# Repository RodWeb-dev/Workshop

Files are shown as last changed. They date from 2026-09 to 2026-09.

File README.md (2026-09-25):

# Workshop — Serre connectée

Un Arduino relève la température, l'humidité et la luminosité, et pilote le ventilateur, le chauffage et l'éclairage.
Il envoie ses mesures par port série à un Raspberry Pi 3, qui les enregistre dans une base SQLite et les affiche sur un tableau de bord web.

```text
Arduino ──(USB / série)──> collect.py ──> serre.db (SQLite) ──> data.php ──> index.php + script.js
```

## Arborescence

```text
WorkShop/
├── arduino/
│   └── codeOK_final.ino
├── impression3d/
│   ├── boitier yanis.stl
│   ├── couvercle yanis.stl
│   ├── helice yanis.stl
│   └── porte yanis.stl
├── raspberry/
│   ├── index.php
│   ├── data.php
│   ├── script.js
│   ├── style.css
│   ├── img/bg.jpg
│   ├── js/chart.umd.min.js
│   ├── db/
│   │   ├── schema.sql
│   │   └── serre.db
│   └── scripts/
│       └── collect.py
├── Dockerfile
└── docker-compose.yml
```

## Arduino

| Fichier | Rôle |
| --- | --- |
| `arduino/codeOK_final.ino` | Lit les capteurs (DHT22 pour la température et l'humidité, BH1750 pour la luminosité), active les équipements selon des seuils et envoie une ligne par mesure sur le port série à 9600 bauds. |

Chaque ligne contient les mesures et l'état des équipements, séparés par `|` :

```text
temp=22.5;hygro=60.0;lux=120.0|Ventilateur=OFF;Chauffage=OFF;Eclairage=ON
```

## Raspberry Pi

### Collecte

| Fichier | Rôle |
| --- | --- |
| `raspberry/scripts/collect.py` | Ouvre le port série (`/dev/ttyACM0`), attend 2 s que l'Arduino redémarre, ignore la première ligne puis lit les trames en continu. Enregistre les mesures dans `readings` et ouvre ou ferme un événement dans `events` à chaque changement d'état d'un équipement. |

### Base de données

| Fichier | Rôle |
| --- | --- |
| `raspberry/db/schema.sql` | Crée les tables et insère les trois équipements. |
| `raspberry/db/serre.db` | Base SQLite (ignorée par git). |

Tables :

- `readings` : une ligne par mesure (`temp`, `hygro`, `lux`, `recorded_at`).
- `equipements` : Ventilateur, Chauffage, Eclairage.
- `events` : périodes de fonctionnement d'un équipement (`started_at`, et `ended_at` qui reste vide tant que l'équipement est allumé).

Créer la base :

```bash
sqlite3 raspberry/db/serre.db < raspberry/db/schema.sql
```

### Tableau de bord web

| Fichier | Rôle |
| --- | --- |
| `raspberry/index.php` | Page principale : onglets température / humidité / luminosité, graphique et un voyant par équipement (généré depuis la table `equipements`). |
| `raspberry/data.php` | API JSON appelée par la page : dernière mesure, équipements actifs, 50 dernières mesures et statistiques par équipement (nombre de cycles, durée cumulée). |
| `raspberry/script.js` | Appelle `data.php` toutes les secondes, met à jour les valeurs, les voyants (classe `on`) et le graphique. |
| `raspberry/style.css` | Styles de la page. Un voyant est rouge par défaut et vert avec la classe `on`. |
| `raspberry/js/chart.umd.min.js` | Bibliothèque Chart.js, embarquée localement pour fonctionner sans internet. |
| `raspberry/img/bg.jpg` | Image de fond. |

## Impression 3D

| Dossier | Rôle |
| --- | --- |
| `impression3d/` | Modèles STL de la serre : boîtier, couvercle, hélice du ventilateur et porte. |

## Développement (Docker)

| Fichier | Rôle |
| --- | --- |
| `Dockerfile` | Image PHP 8.2 + Apache qui sert le dossier `raspberry/`. |
| `docker-compose.yml` | Lance le conteneur derrière Traefik, accessible sur `http://raspberry.test`. Le dossier `raspberry/` est monté en volume pour voir les modifications en direct. |

```bash
docker compose up -d --build
```

## Déploiement sur le Raspberry Pi

Le projet est développé dans le conteneur, puis copié sur le Raspberry Pi 3 par SSH.
Sur le Pi, il faut un serveur web avec PHP et l'extension SQLite3, ainsi que Python 3 avec `pyserial` pour `collect.py` :

```bash
python3 raspberry/scripts/collect.py
```

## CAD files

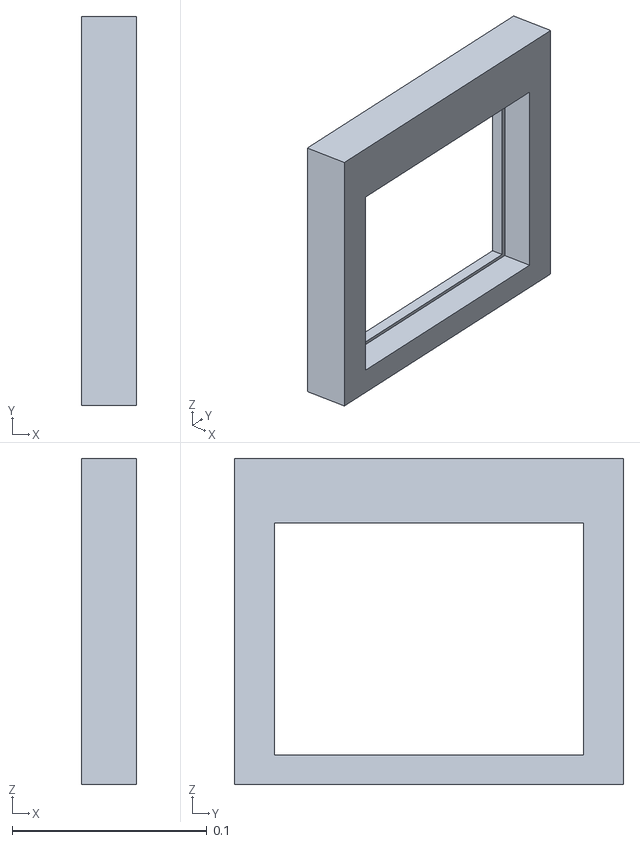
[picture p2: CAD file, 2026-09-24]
impression3d/porte yanis.stl
0.0281 x 0.2 x 0.168

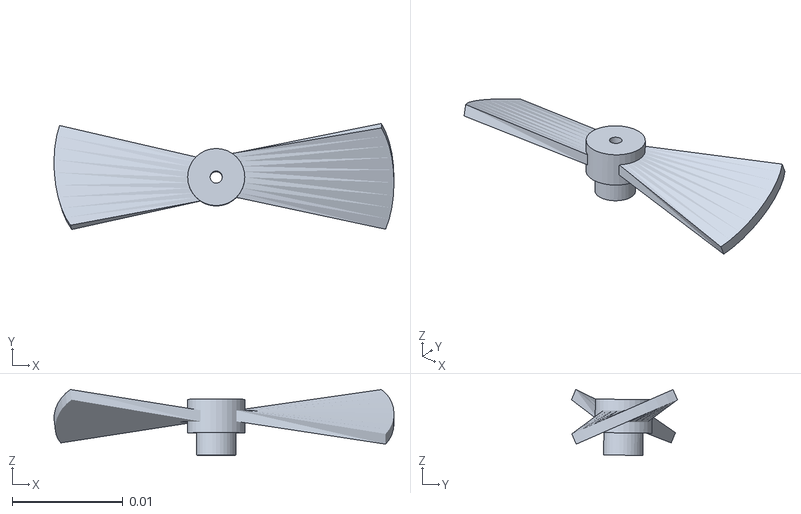
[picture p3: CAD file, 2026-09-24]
impression3d/helice yanis.stl
0.0308 x 0.0096 x 0.00597

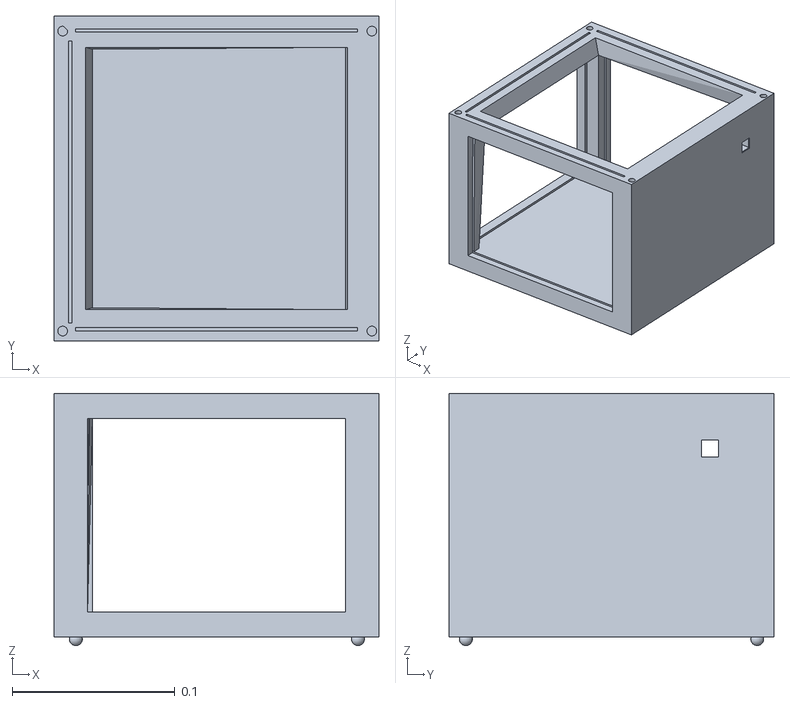
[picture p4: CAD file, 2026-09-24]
impression3d/boitier yanis.stl
0.2 x 0.2 x 0.155

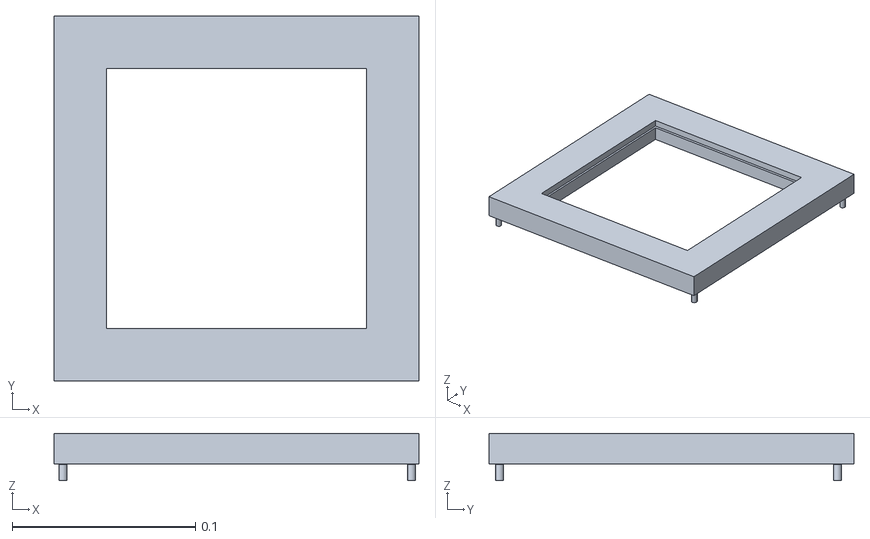
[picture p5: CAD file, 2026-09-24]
impression3d/couvercle yanis.stl
0.199 x 0.199 x 0.0258

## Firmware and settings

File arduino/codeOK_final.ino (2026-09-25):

#include <Wire.h>
#include <BH1750.h>
#include <DHT.h>

// --- Pins ---
const int LED1 = 4;
const int LED2 = 6;

const int FAN_ENA = 5;       // ENA L298N -> vitesse ventilateur
const int FAN_IN1 = 7;       // IN1 L298N
const int FAN_IN2 = 8;       // IN2 L298N

const int HEATER_PIN = 9;    // chauffage
const int DHTPIN = 2;

#define DHTTYPE DHT22        // mets DHT11 si besoin

// --- Seuils ---
const float SEUIL_LUM = 20;
const float T_CHAUFFE = 10 ;
const float T_STOP_CHAUFFE = 20;

const float T_VENTILO_MIN = 23;
const float T_VENTILO_MAX = 30;

BH1750 lightMeter;
DHT dht(DHTPIN, DHTTYPE);

bool chauffageOn = false;

void setup() {

  Serial.begin(9600);

  pinMode(LED1, OUTPUT);
  pinMode(LED2, OUTPUT);

  pinMode(FAN_ENA, OUTPUT);
  pinMode(FAN_IN1, OUTPUT);
  pinMode(FAN_IN2, OUTPUT);

  pinMode(HEATER_PIN, OUTPUT);

  digitalWrite(LED1, LOW);
  digitalWrite(LED2, LOW);

  digitalWrite(FAN_IN1, LOW);
  digitalWrite(FAN_IN2, LOW);

  analogWrite(FAN_ENA, 0);

  

  Wire.begin();
  dht.begin();

  if (lightMeter.begin(BH1750::CONTINUOUS_HIGH_RES_MODE)) {
    Serial.println("BH1750 OK");
  } else {
    Serial.println("BH1750 introuvable");
  }
}

void loop() {

  // ========== LUMIERE -> LED ==========

  float lux = lightMeter.readLightLevel();

  // Etat Eclairage
  bool eclairageOn;

  if (lux < SEUIL_LUM) {

    digitalWrite(LED1, HIGH);
    digitalWrite(LED2, HIGH);

    eclairageOn = true;

  } else {

    digitalWrite(LED1, LOW);
    digitalWrite(LED2, LOW);

    eclairageOn = false;
  }


  // ========== TEMPERATURE + HUMIDITE ==========

  float temp = dht.readTemperature();
  float hygro = dht.readHumidity();

  if (!isnan(temp) && !isnan(hygro)) {

    // ===== CHAUFFAGE =====

    if (temp < T_CHAUFFE) {
      chauffageOn = true;
      digitalWrite(HEATER_PIN,LOW);
  }

    if (temp >= T_STOP_CHAUFFE) {
      chauffageOn = false;
      digitalWrite(HEATER_PIN,HIGH);
    }


    // ===== VENTILATEUR =====

    int vitesseVentilo = 0;

    // Moins de 23°C -> 0%
    if (temp < 23) {

      vitesseVentilo = 0;

    }

    // 23°C à moins de 25°C -> environ 20%
    else if (temp >= 23 && temp < 25) {

      vitesseVentilo = 20;

    }

    // 25°C à moins de 27°C -> environ 31%
    else if (temp >= 25 && temp < 27) {

      vitesseVentilo = 30;

    }

    // 27°C à moins de 29°C -> environ 47%
    else if (temp >= 27 && temp < 29) {

      vitesseVentilo = 40;

    }

    // 29°C ou plus -> maximum 60%
    else {

      vitesseVentilo = 50;

    }


    // ===== SECURITE =====

    // Pas de chauffage quand le ventilateur fonctionne
    //if (vitesseVentilo > 0) {
    //  chauffageOn = false;
    //}


    // ===== COMMANDE VENTILATEUR =====

    if (vitesseVentilo > 0) {

      digitalWrite(FAN_IN1, HIGH);
      digitalWrite(FAN_IN2, LOW);

      analogWrite(FAN_ENA, vitesseVentilo);

    } else {

      digitalWrite(FAN_IN1, LOW);
      digitalWrite(FAN_IN2, LOW);

      analogWrite(FAN_ENA, 0);
    }


    // ===== CHAUFFAGE =====

   digitalWrite(
    HEATER_PIN,
      chauffageOn ? LOW : HIGH
    );


    // ==================================================
    // AFFICHAGE ORGANISE POUR LA BASE DE DONNEES
    // ==================================================

    // ----- GROUPE GAUCHE : readings -----

    Serial.print("temp = ");
    Serial.print(temp, 1);

    Serial.print(" ; ");

    Serial.print("hygro = ");
    Serial.print(hygro, 1);

    Serial.print(" ; ");

    Serial.print("lux = ");
    Serial.print(lux, 1);


    // ----- SEPARATION -----

    Serial.print(" | ");


    // ----- GROUPE DROITE : equipments -----

    Serial.print("Ventilateur = ");

    if (vitesseVentilo > 0) {
      Serial.print("ON");
    } else {
      Serial.print("OFF");
    }

    Serial.print(" ; ");

    Serial.print("Chauffage = ");
    Serial.print(chauffageOn ? "ON" : "OFF");

    Serial.print(" ; ");

    Serial.print("Eclairage = ");
    Serial.println(eclairageOn ? "ON" : "OFF");
  }


  // ========== ERREUR DHT ==========

  else {

    Serial.print("temp = ERROR ; ");

    Serial.print("hygro = ERROR ; ");

    Serial.print("lux = ");
    Serial.print(lux, 1);

    Serial.print(" | ");

    Serial.print("Ventilateur = ERROR");
    Serial.print(" ; ");

    Serial.print("Chauffage = ERROR");
    Serial.print(" ; ");

    Serial.println("Eclairage = ERROR");
  }

  delay(1000);
}

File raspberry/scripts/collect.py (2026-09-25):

# --- collect.py ---

import pathlib
import sqlite3
import time

import serial

path = pathlib.Path(__file__).parent.parent.resolve()

timeout = 3  # Délai d'attente pour la lecture du port série
rate = 9600  # Vitesse de communication du port série
port = "/dev/ttyACM0"  # Port série à utiliser

db = sqlite3.connect(path / "db/serre.db")
db.execute("PRAGMA foreign_keys = ON")

print("db connected")

equipements = {}
db_equipements = db.execute("SELECT id, name FROM equipements").fetchall()
for equipement_id, name in db_equipements:
    equipements[name] = {"ID": equipement_id, "Etat": False, "Event_id": None}


# Insérer les données dans la table readings
def insert_real_data(data):
    cursor = db.cursor()
    cursor.execute(
        "INSERT INTO readings (temp, hygro, lux) VALUES (?, ?, ?)",
        (data["temp"], data["hygro"], data["lux"]),
    )
    db.commit()


# Démarrer un événement dans la table events
def start_event(
    equipement_id,
):
    cursor = db.cursor()
    cursor.execute("INSERT INTO events (equipement_id) VALUES (?)", (equipement_id,))
    db.commit()
    return cursor.lastrowid


# Terminer un événement dans la table events
def end_event(
    event_id,
):
    cursor = db.cursor()
    cursor.execute(
        "UPDATE events SET ended_at = CURRENT_TIMESTAMP WHERE id = ?",
        (event_id,),
    )
    db.commit()


# parser les les données réelles reçues depuis le port série
def parse_real(text):
    real = text.split("|")[0]
    data = {}
    real = real.split(";")
    for paire in real:
        cle, valeur = paire.split("=")
        cle = cle.strip()
        valeur = valeur.strip()
        data[cle] = float(valeur)
    return data


# détecter les changements d'état des équipements et déclencher un événement si nécessaire
def parse_binary(text):
    binary = text.split("|")[1]
    binary = binary.split(";")
    for paire in binary:
        cle, valeur = paire.split("=")
        cle = cle.strip()
        valeur = valeur.strip()
        if valeur == "ON" and not equipements[cle]["Etat"]:
            equipements[cle]["Etat"] = True
            equipements[cle]["Event_id"] = start_event(equipements[cle]["ID"])
        elif valeur == "OFF" and equipements[cle]["Etat"]:
            equipements[cle]["Etat"] = False
            end_event(equipements[cle]["Event_id"])
            equipements[cle]["Event_id"] = None


# Lires les données depuis le port série
with serial.Serial(port, rate, timeout=timeout) as ser:
    print("Serial port opened")
    time.sleep(2)  # Attendre que le port série soit prêt
    reset = ser.reset_input_buffer()  # Réinitialiser le tampon d'entrée
    ser.readline()  # Lire la première ligne pour ignorer les données initiales
    while True:
        line = ser.readline()
        if line:
            print(f"Received: {line}")
            text = line.decode("utf-8", errors="ignore").strip()
            if text:
                try:
                    print(f"Parsed: {text}")
                    data = parse_real(text)
                    insert_real_data(data)
                    parse_binary(text)
                except (ValueError, KeyError, IndexError) as e:
                    print(f"Error parsing line: {e}")
                    print(f"Line content: {text}")

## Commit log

2026-09-24 modeles 3d
    [boitier yanis.stl, couvercle yanis.stl, helice yanis.stl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]
2026-09-25 code arduino
